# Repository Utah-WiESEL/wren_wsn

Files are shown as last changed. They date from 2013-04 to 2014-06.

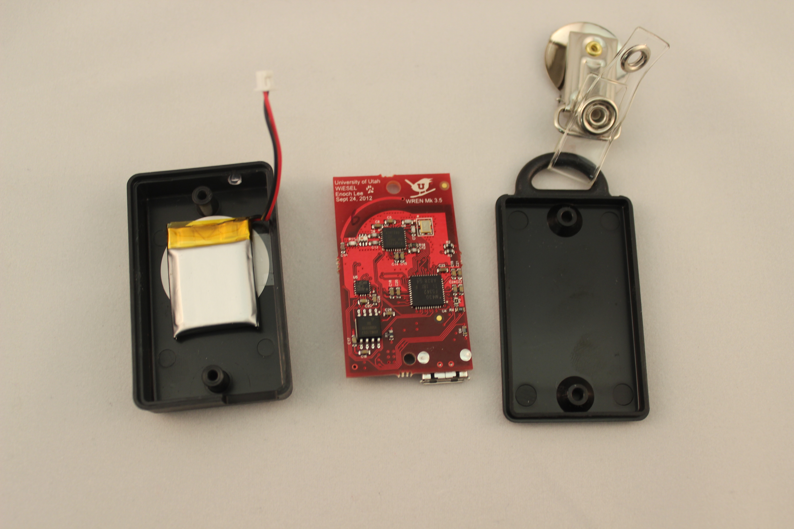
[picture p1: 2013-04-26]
wren_mote/images/image2.JPG

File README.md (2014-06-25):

wren_wsn
========

Wireless Ranging Enabled Node (WREN) is a new low cost, TinyOS compatible platform. Our main goal is to create a scalable WSN for human contact data for disease spreading simulations. This platform solves several issues when compared to commercially available sensors, such as the TelosB and Irene, in scaling and rapid deployment strategies. It also requires little maintenance and does not need an existing support infrastructure.

The low cost and maintainability allow it to easily scale to a network of thousands of motes. It is built with consideration that the end user may not have technical/engineering knowledge of the system. Deploying a network this large takes less than one hour and recovery is just as simple, leading to a rapid data download process for fast, repeatable deployments.

The system has several proximity based use cases besides contact networks. Other features such as motion tracking using the accelerometer, radio strength signal indication (RSSI), and low power usage can be made advantageous for several projects.

The purpose of this Wiki is to provide the source for our hardware, software, and instructions to get the system up and running.

For more info:

http://wiesel.ece.utah.edu/media/documents/pdf/2012/12/13/sensys-demo-2012.pdf

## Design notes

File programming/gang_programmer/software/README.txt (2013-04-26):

When programming, if only one WREN is attached,
	Disable all other 'open' ports.

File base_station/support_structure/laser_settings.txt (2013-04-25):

Laser Cutter Specs:
	60w
	Auto Focus (on)

1/4 in. wood (light color)
	speed:		30-34%
	power:		100%
	frequency:	500Hz
	
1/8 in. acrylic (clear)
	speed:		20%
	power:		100%
	frequency:	5000Hz
	
1/16 in. acrylic (clear)
	speed:		35%
	power:		40%
	frequency:	5000Hz

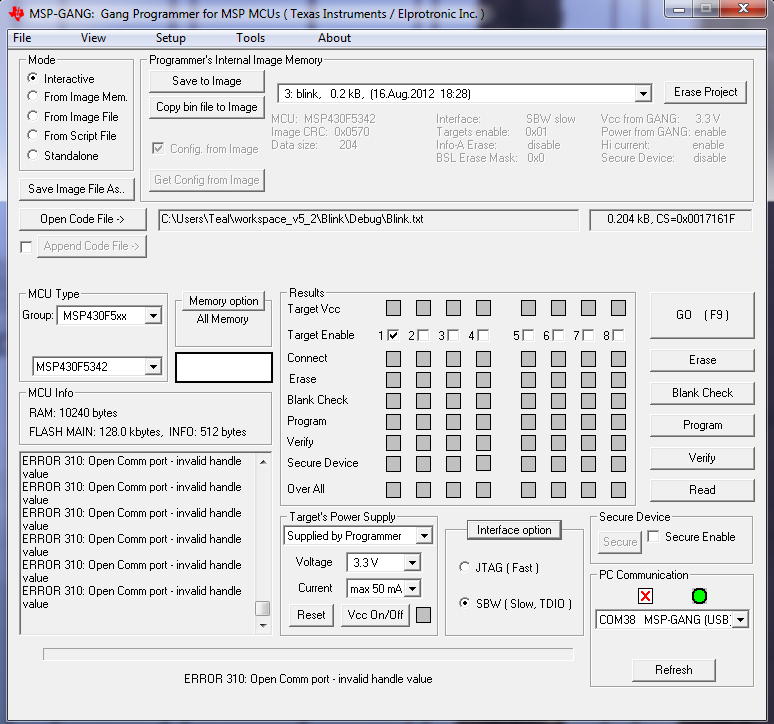
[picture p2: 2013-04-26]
programming/gang_programmer/software/Main Program.PNG

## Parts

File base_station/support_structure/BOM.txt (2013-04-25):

Bill of Materials (1x Base Station):

Wood (if using a laser, wood lighter in color will cut cleaner):

	Birch Project Panel Plywood:
		1/4 in. x 2 ft. x 4 ft. (x2)
	
	Dowels:
		1/2 in. x 48 in. (x6)

Hardware:
	Wood Screws:
		#4 x 1/2 in. Flat Head Phillips (30x) - used to mount PCB blades onto wood base
		
		#6 x 1 in. Flat Head Phillips (12x) - used to mount stack legs onto wooden base
		
	Drywall Screws:
		1-1/4 x 8 GA Coarse Thread (16x) - used to mount wooded support onto wooded base
	
	Power Mounting - used for mounting PSU and AC connector onto wooden base
		Switch Plate Screws:
			#6-32 x 1 in.  (x4)
	
		Machine Screw Nuts:
			#6-32 (x4)
			
		Flat Washers:
			#6 (x8)
	
Glue:
	Any generic wood glue

Other:

	Trim Tray - used for diluting wood glue
	Small Paint Brushes - used for applying glue
	Rags - used to wipe off excess glue

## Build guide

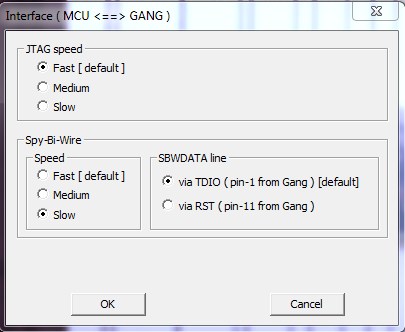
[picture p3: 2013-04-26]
programming/gang_programmer/software/Setup - Interface.PNG

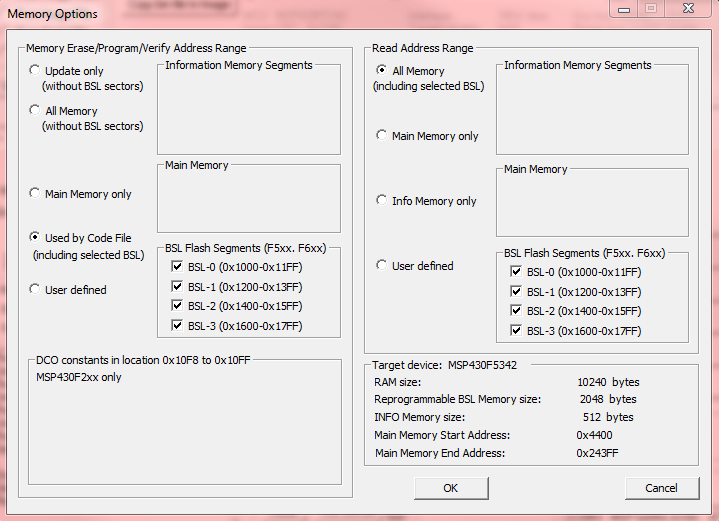
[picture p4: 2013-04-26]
programming/gang_programmer/software/Setup - Memory Options - For BSL.PNG

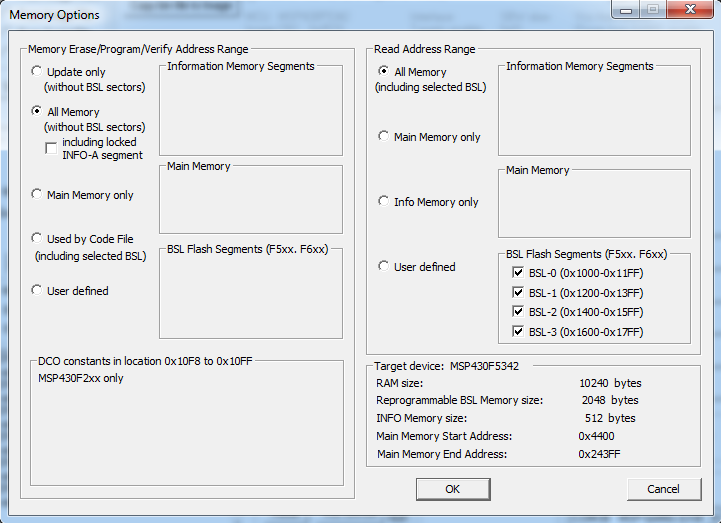
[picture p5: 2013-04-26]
programming/gang_programmer/software/Setup - Memory Options - For Others.PNG

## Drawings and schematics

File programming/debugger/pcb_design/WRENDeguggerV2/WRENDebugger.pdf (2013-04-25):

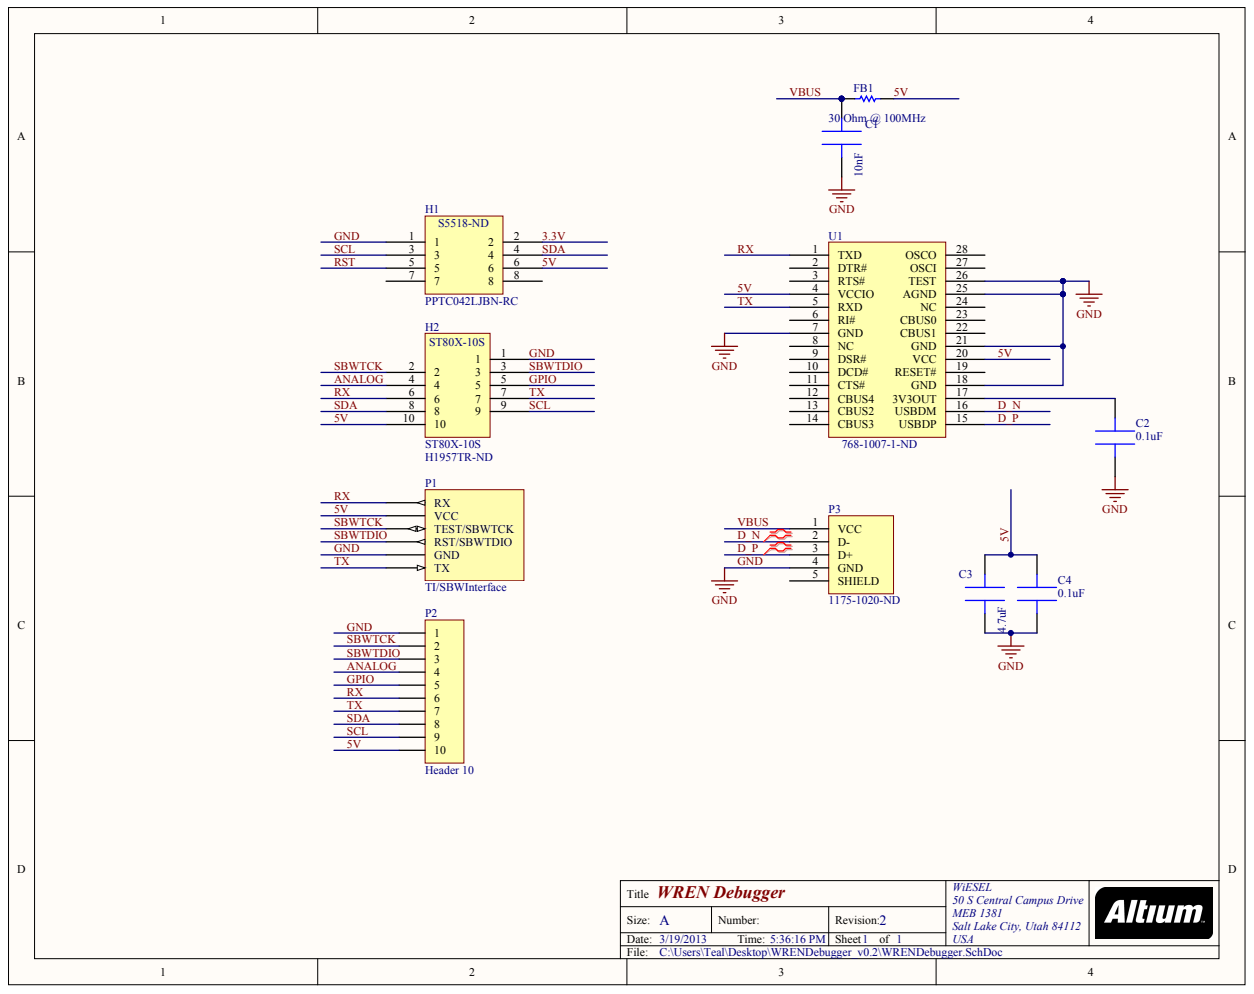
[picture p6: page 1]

WREN Debugger Title | WiESEL 50 S Central Campus Drive MEB 1381 Salt Lake City, Utah 84112 USA

Size: A | Number: | Revision: 2
Date: 3/19/2013 Time: 5:36:16 PM | | Sheet 1 of 1

C:\Users\Teal\Desktop\WRENDebugger_v0.2\WRENDebugger.SchDoc

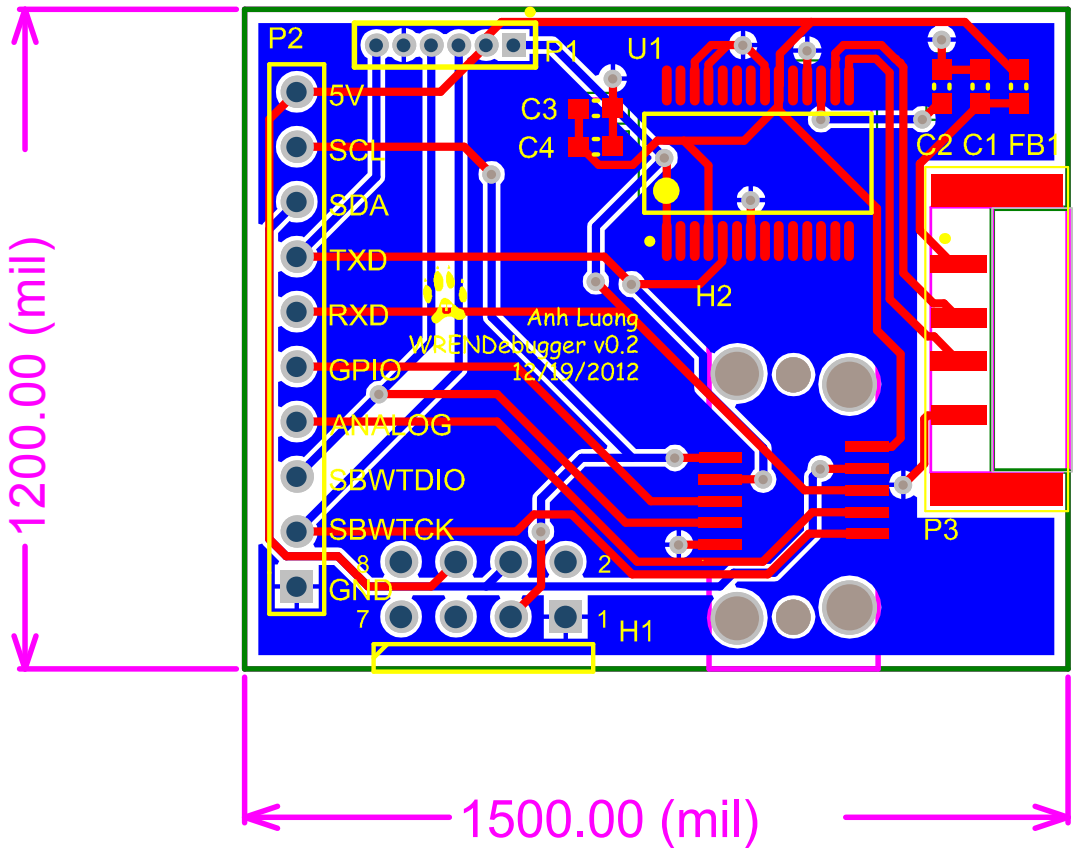
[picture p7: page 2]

Description | Footprint | Quantity | Supplier Part Number 1
MURATA - GRM188R71H103KA01D -CAPACITOR, 0603, 10NF, 50V, REEL 4000 | CAPC1608X09N (0603) | 1
Capacitor 0603 0.1uF | CAPC1608X09N (0603) | 2
CAP CER 4.7UF 6.3V Y5V 0603 | CAPC1608X09N (0603) | 1
FERRITE CHIP BEAD 30 OHM SMD | CAPC1608X09N (0603) | 1 | 445-2181-2-ND
CONN FEMALE 8POS DL .1" R/A TIN | S5518-ND | 1
CONN PLUG 10POS VERT CRADLE SMD | ST80X-10S | 1 | H1957TR-ND
TI MSP430 Programming Interface | SAMTEC/ SMS-106-01-G-S | 1
Header, 10-Pin | HDR1X10 | 1
CONN USB A TYPE ULTRA FLAT T/ H | usbA | 1 | 1175-1020-ND
IC USB FS SERIAL UART 28-SSOP | SOP65P780X200-28N | 1 | 768-1007-1-ND

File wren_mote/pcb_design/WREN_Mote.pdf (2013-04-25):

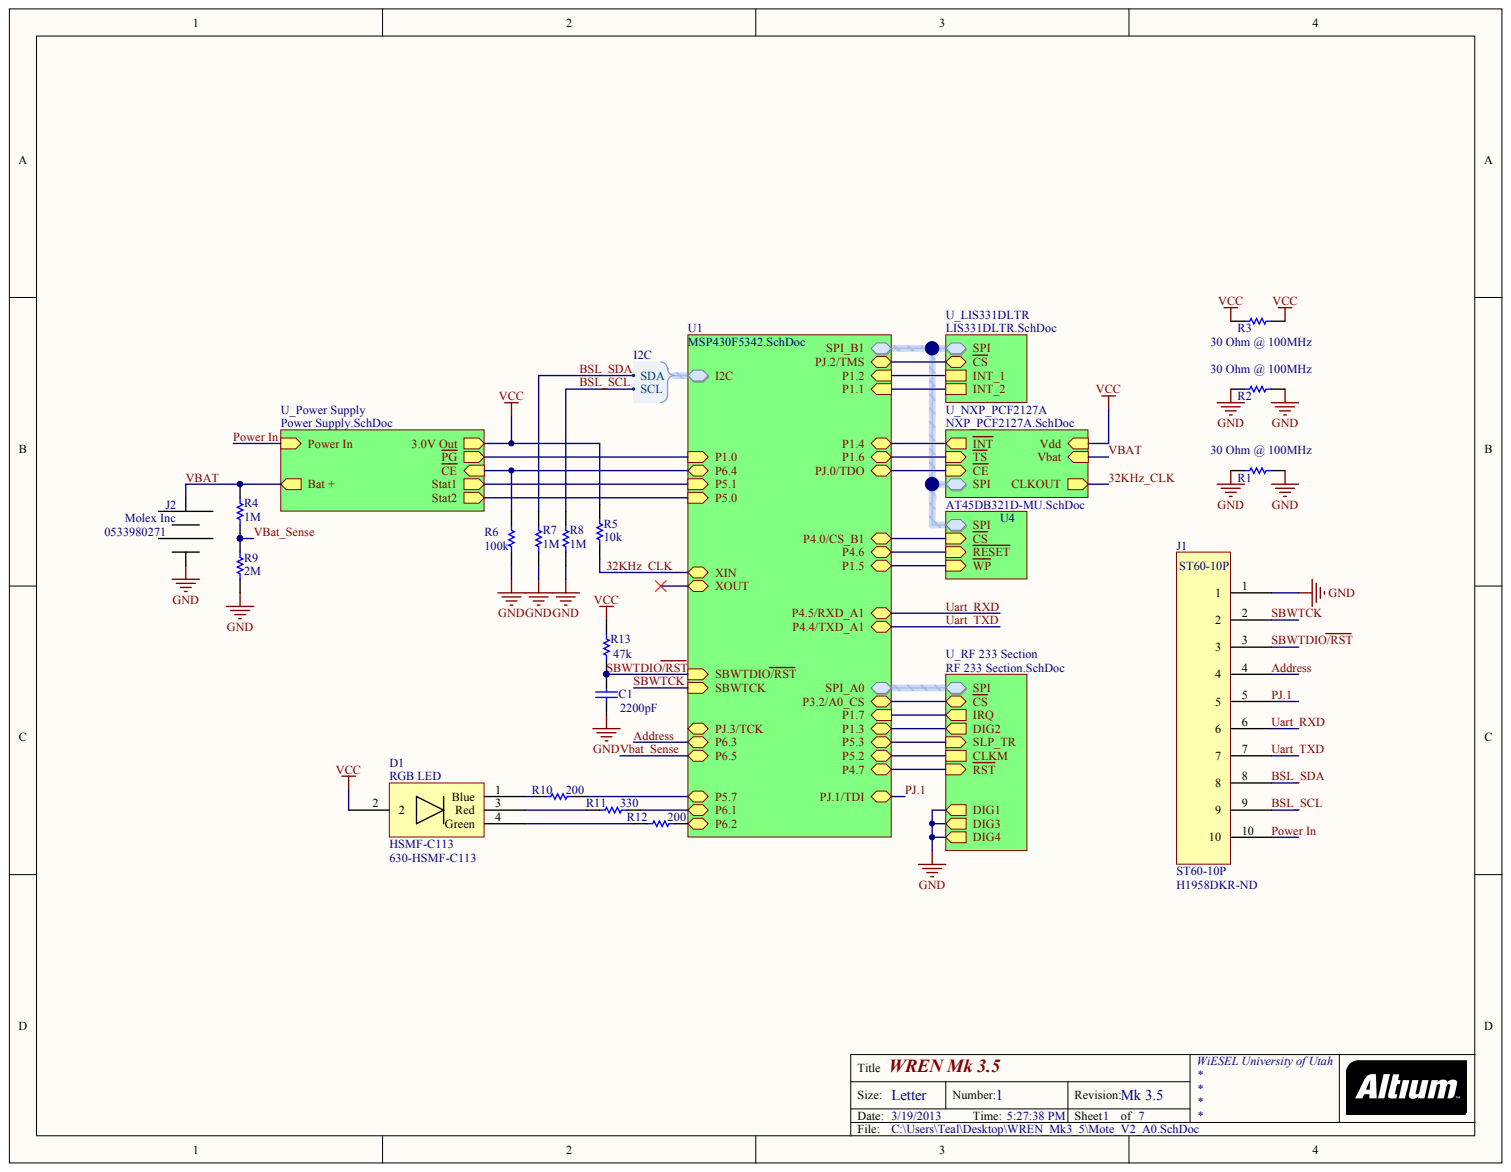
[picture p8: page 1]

P430F5342.SchDoc
PJ.0/TDO PJ.1/TDI PJ.2/TMS

U_Power Supply Power Supply.SchDoc

32KHz_CLK
Power In SBWTCK SBWTDIO/RS

PJ.3/TCK SBWTDIO/RS
SBWTCK

WiESEL University of Utah *** *

Letter | Revision:

3/19/2013 Time: 5:27:38 P M | Sheet of

C:\Users\Teal\Desktop\WREN_Mk3_5\Mote_V2_A0.SchDoc

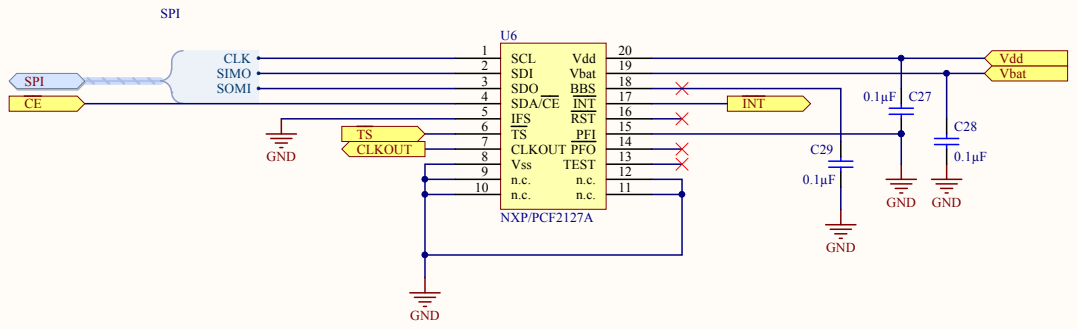
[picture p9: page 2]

n.c.

WiESEL University of Utah ***

C:\Users\Teal\Desktop\WREN_Mk3_5\NXP_PCF2127A.SchDoc

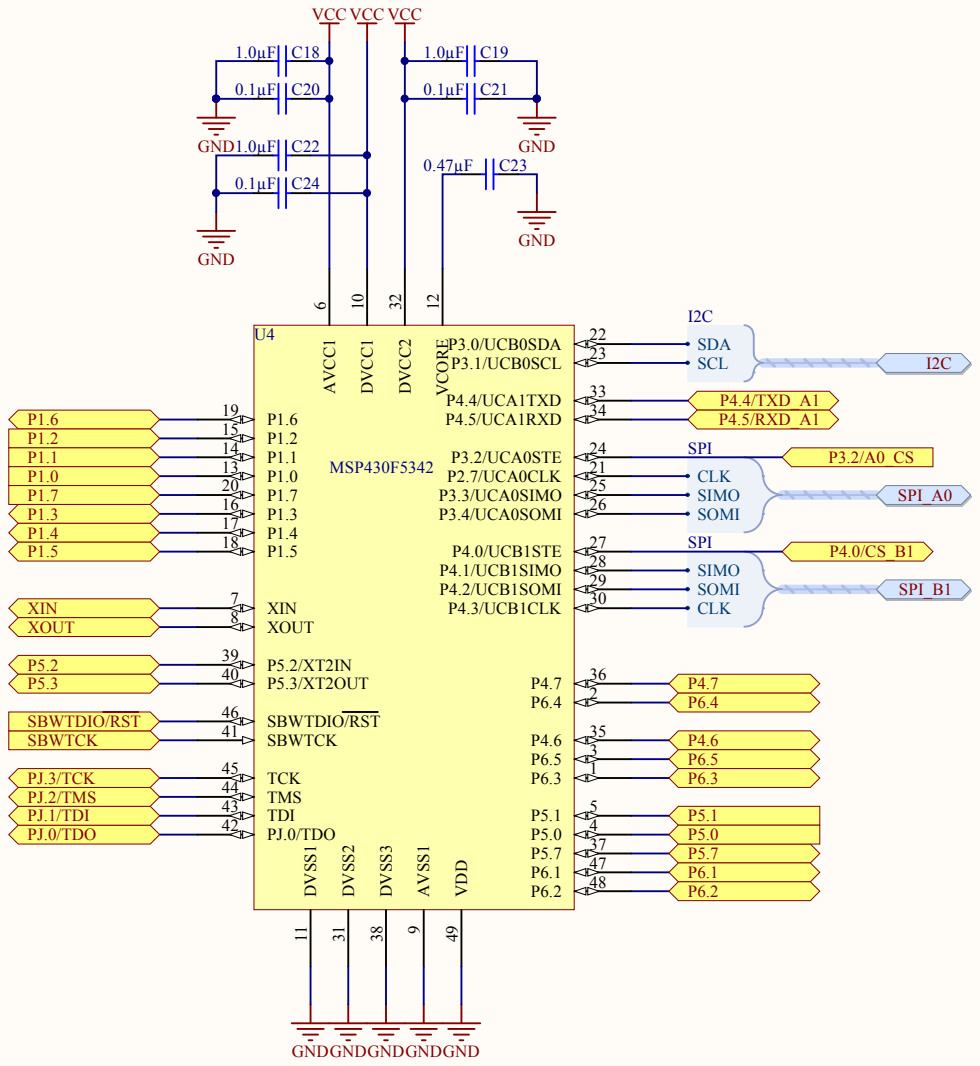
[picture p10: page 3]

Title WREN Mk 3.5 | WiESEL University of Utah *

Size: | Number: 3 | Mk 3.5

Date: 3/19/2013 Time: 5:27:38 PM | | Sheet of 7

C:\Users\Teal\Desktop\WREN_Mk3_5\MSP430F5342.SchDoc

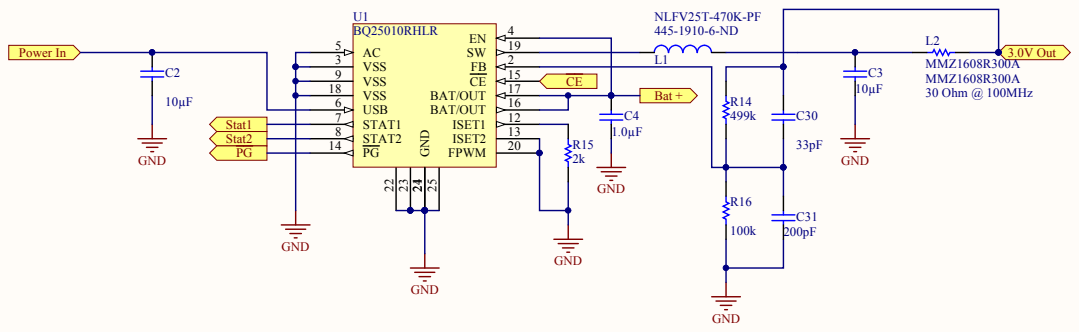
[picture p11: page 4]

WiESEL University of Utah ***

C:\Users\Teal\Desktop\WREN_Mk3_5\Power Supply.SchDoc

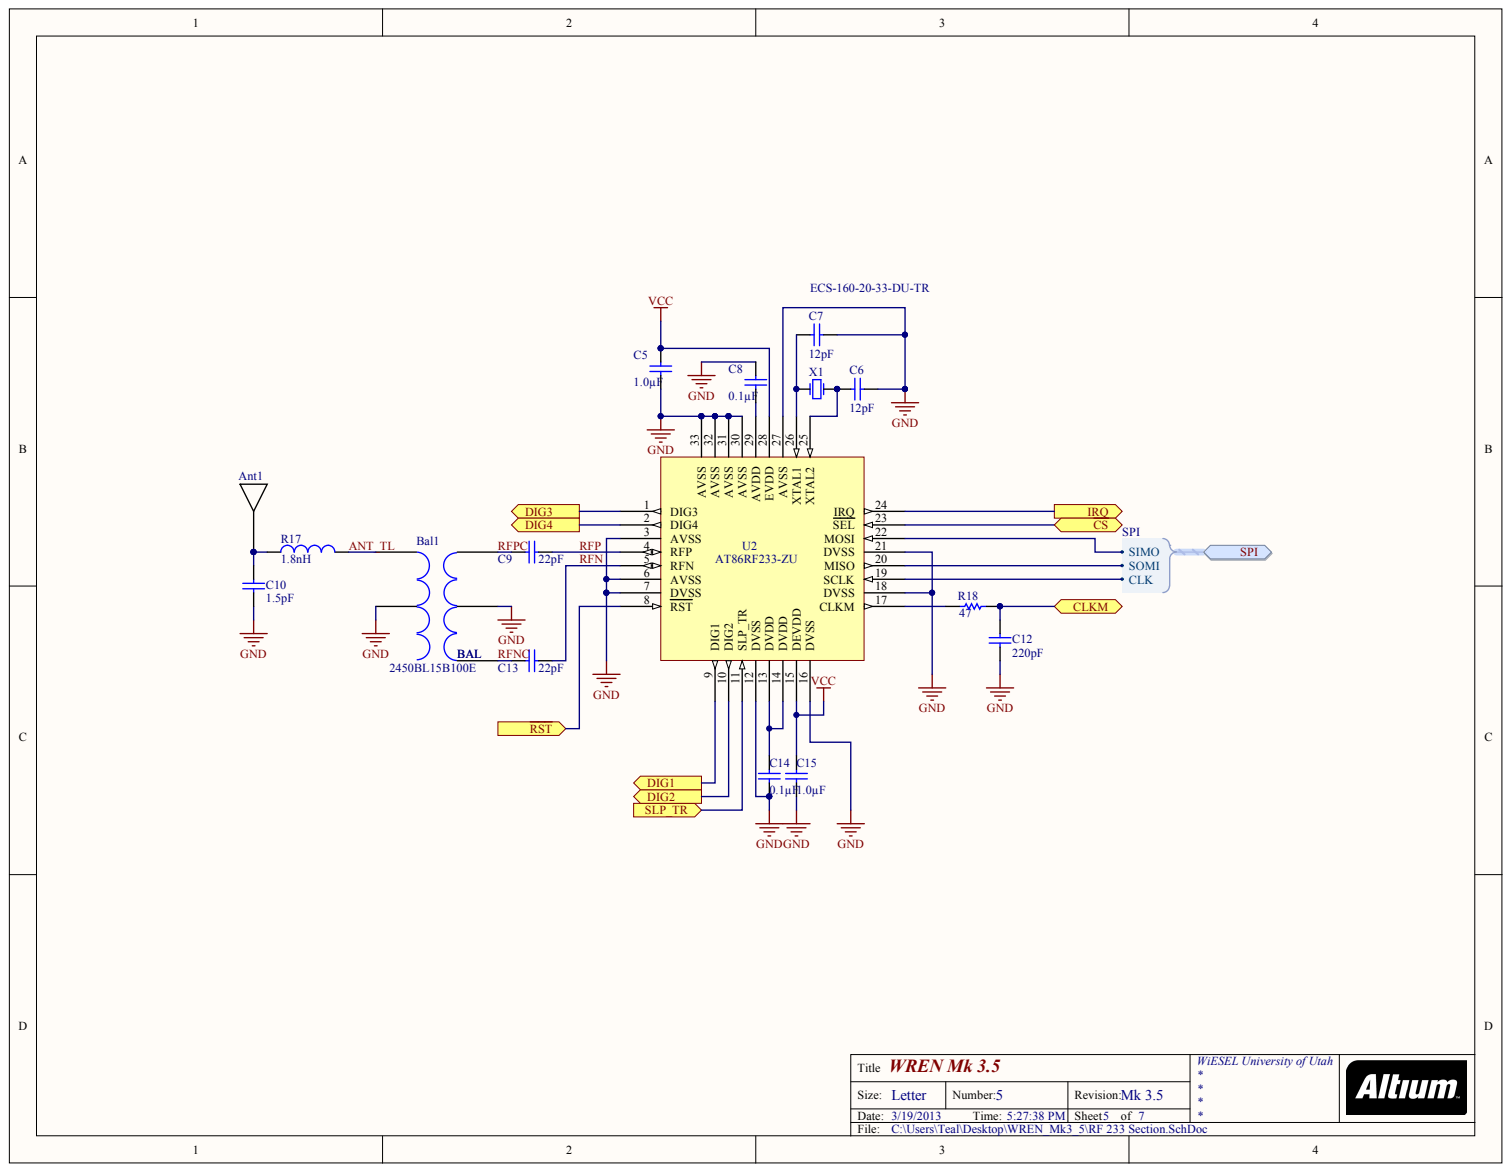
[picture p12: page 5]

TAL2 25 XTAL1 26 AVSS 27 EVDD 28 AVDD 29 AVSS 30 AVSS 31 AVSS 32 AVSS 33

DVSS 16 CLKM 17 DVSS 18 SCLK 19 MISO 20 DVSS 21 MOSI 22 SEL 23 IRQ X

RFP 4

RFN | RFN 5

AVSS 6

RST 8

Title WREN Mk 3.5 | WiESEL University of Utah *

Size: | Number: 5 | Mk 3.5

Date: 3/19/2013 Time: 5:27:38 PM | | Sheet of 7

C:\Users\Teal\Desktop\WREN_Mk3_5\RF 233 Section.SchDoc

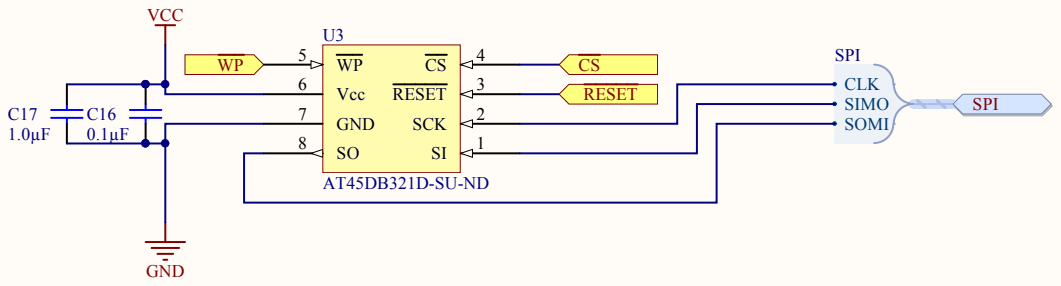
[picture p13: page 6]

WiESEL University of Utah ***

C:\Users\Teal\Desktop\WREN_Mk3_5\AT45DB321D-MU.SchDoc

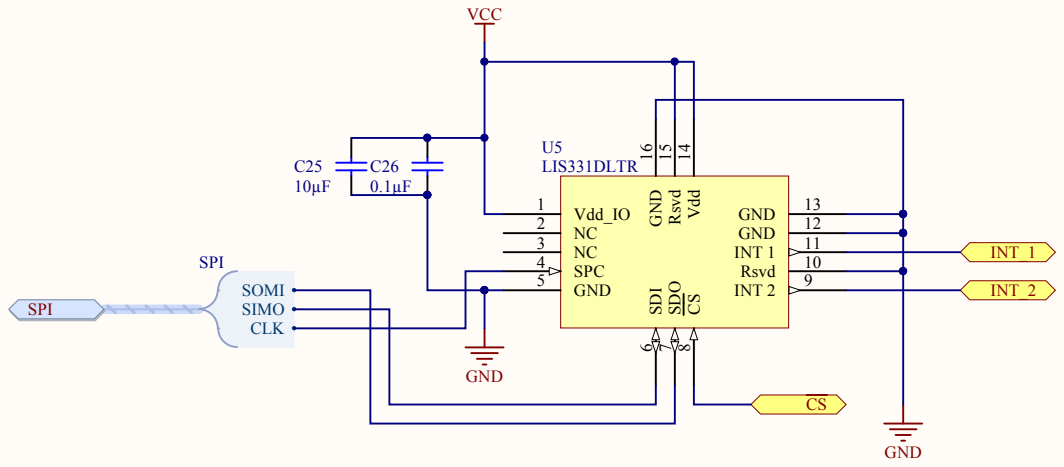
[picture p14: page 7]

WiESEL University of Utah ***

C:\Users\Teal\Desktop\WREN_Mk3_5\LIS331DLTR.SchDoc

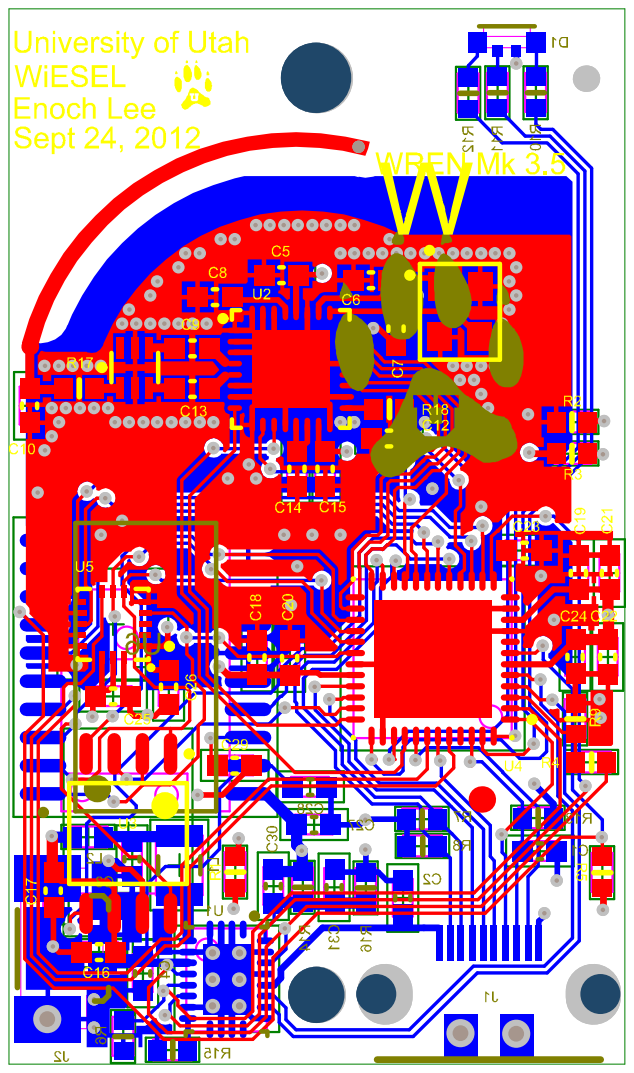
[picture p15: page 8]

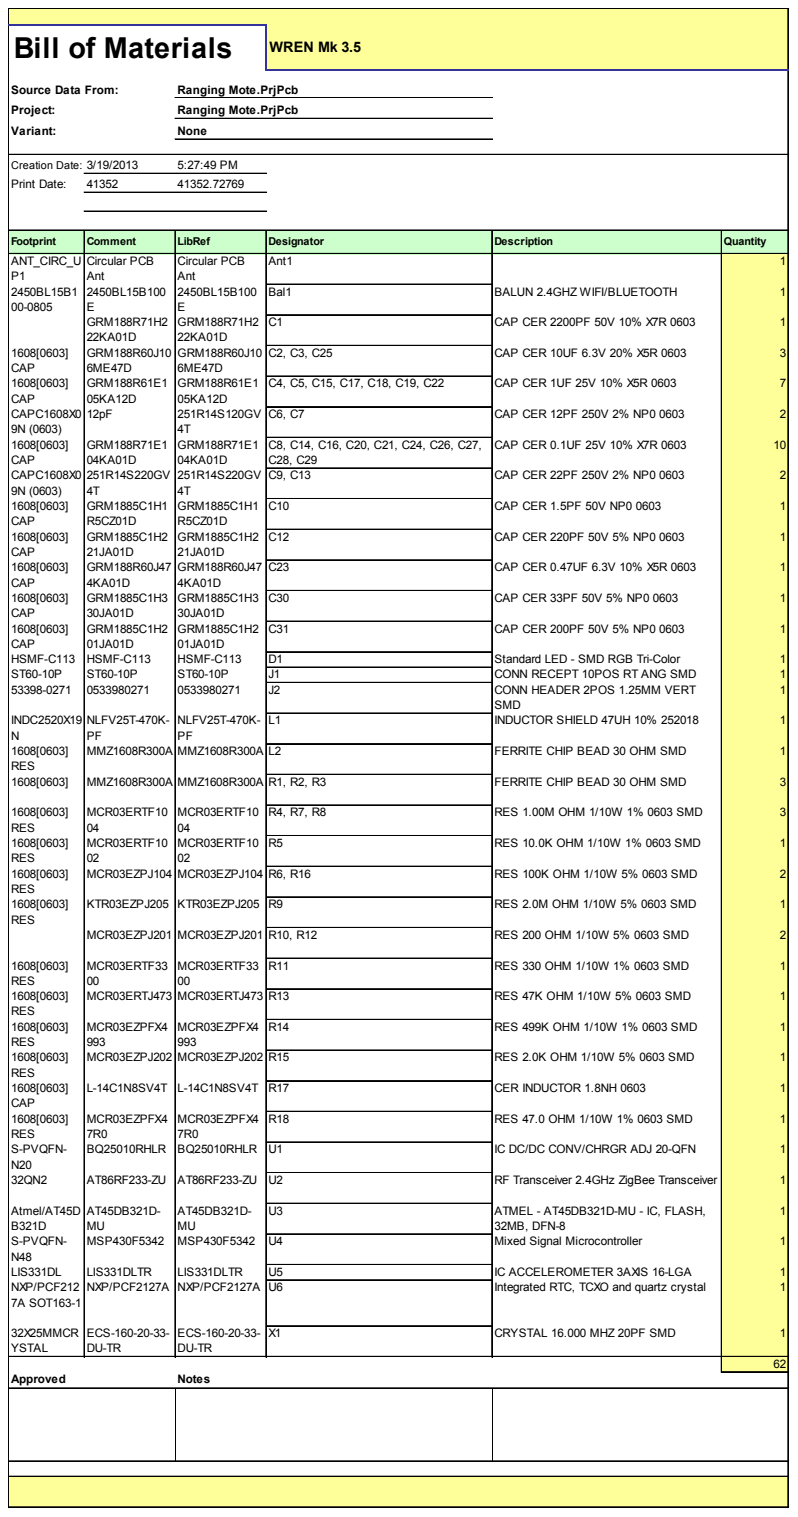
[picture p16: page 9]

Footprint | Comment | LibRef | Designator | Description | Quantity

Ant1 | | 1

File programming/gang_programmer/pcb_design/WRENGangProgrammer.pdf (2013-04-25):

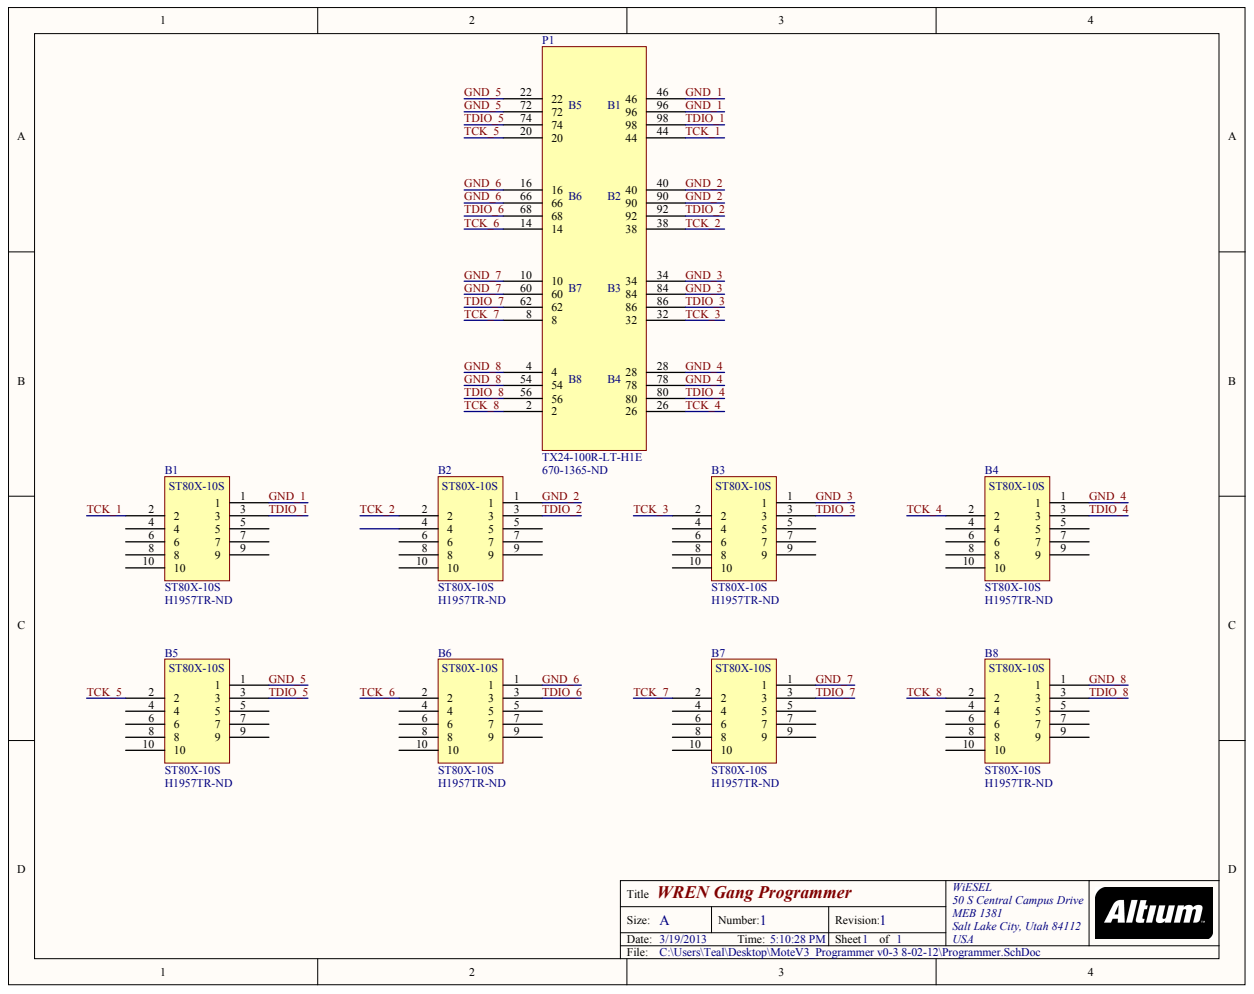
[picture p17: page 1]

WREN Gang Programmer Title | WiESEL 50 S Central Campus Drive MEB 1381 Salt Lake City, Utah 84112 USA

Size: A | Number: 1 | Revision: 1
Date: 3/19/2013 Time: 5:10:28 PM | | Sheet 1 of 1

C:\Users\Teal\Desktop\MoteV3_Programmer v0-3 8-02-12\Programmer.SchDoc


Comment | Description | Designator | Footprint | LibRef | Quantity

ST80X-10S | CONN PLUG 10POS VERT CRADLE SMD | B1, B2, B3, B4, B5, B6, B7, B8 | ST80X-10S | ST80X-10S | 8

TX24-100R-LT-H1E | CONN RCPT 1.27MM 100P1 | | TX24-100R-LT-H1E | TX24-100R-LT-H1E | 1

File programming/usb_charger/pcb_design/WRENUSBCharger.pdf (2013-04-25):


WREN USB Charger Title | WiESEL 50 S Central Campus Drive MEB 131 Salt Lake City, Utah 84112 USA

Size: A | Number: 1 | Revision: 1
Date: 3/19/2013 Time: 5:15:56 PM | | Sheet 1 of 1

C:\Users\Teal\Desktop\WRENUSBCharger\WRENUSBCharger.SchDoc


Comment | Description | Designator | Footprint | LibRef | Quantity

ST80X-10S | CONN PLUG 10POS VERT CRADLE SMD | H1 | ST80X-10S | ST80X-10S | 1

1002-015-01001 | CONN USB A TYPE ULTRAH2 | | usbA | 1002-015-01001 | 1

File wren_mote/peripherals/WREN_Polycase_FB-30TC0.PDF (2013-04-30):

TRUE R.058; TRUE R.032; SCALE:2:1; SHEET 1 OF 1

UNLESS OTHERWISE SPECIFIED: DIMENSIONS ARE IN MILLIMETERS SURFACE FINISH: TOLERANCES: LINEAR: ANGULAR: | FINISH: | DEBUR AND BREAK SHARP EDGES | DO NOT SCALE DRAWING | REVISION

NAME | SIGNATURE | DATE | | | | TITLE:
Q.A | | | | MATERIAL: | FB-30TC0 WEIGHT: DWG NO. | A2

DRAWN
CHK'D
APPV'D
MFG

SolidWorks Student Edition.
For Academic Use Only.



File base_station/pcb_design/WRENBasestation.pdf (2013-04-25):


WREN Basestation Title | WiESEL 50 S Central Campus Drive MEB 1381 Salt Lake City, Utah 84115 USA

Size: B | Number: | Revision: 3

Date: 3/19/2013 Time: 5:31:47 PM | | Sheet 1 of 1
File: C:\Users\Teal\Desktop\Mote_BaseStation_v0.3\BaseStation.SchDoc



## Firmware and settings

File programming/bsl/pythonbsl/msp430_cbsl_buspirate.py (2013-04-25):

#!/usr/bin/env python
# encoding: utf-8
"""
Copyright (c) 2013, University of Utah - Electrical and Computer Engineering - WiESEL
All rights reserved.

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
THIS SOFTWARE IS PROVIDED BY THE COPYRIGHT HOLDERS AND CONTRIBUTORS "AS IS" AND
ANY EXPRESS OR IMPLIED WARRANTIES, INCLUDING, BUT NOT LIMITED TO, THE IMPLIED
WARRANTIES OF MERCHANTABILITY AND FITNESS FOR A PARTICULAR PURPOSE ARE
DISCLAIMED. IN NO EVENT SHALL WiESEL BE LIABLE FOR ANY
DIRECT, INDIRECT, INCIDENTAL, SPECIAL, EXEMPLARY, OR CONSEQUENTIAL DAMAGES
(INCLUDING, BUT NOT LIMITED TO, PROCUREMENT OF SUBSTITUTE GOODS OR SERVICES;
LOSS OF USE, DATA, OR PROFITS; OR BUSINESS INTERRUPTION) HOWEVER CAUSED AND
ON ANY THEORY OF LIABILITY, WHETHER IN CONTRACT, STRICT LIABILITY, OR TORT
(INCLUDING NEGLIGENCE OR OTHERWISE) ARISING IN ANY WAY OUT OF THE USE OF THIS
SOFTWARE, EVEN IF ADVISED OF THE POSSIBILITY OF SUCH DAMAGE.
"""

########################################################################
### I2C Bootstrap Loader software for the msp430 embedded proccessor
###
### Anh Luong
### Based on Chris Liechti cc430 2010-04-11
### fixes from Colin Domoney
### cc430 port by Mark Hays 2010-04-11
### Based on tos-bsl version 1.39-telos-8
###

#'''exec' python $0 ${1+"$@"}
#'''
#'

import os, sys, time, string
#sys.path.append("/usr/lib/tinyos")
#//sys.path.append(os.environ.get("OSIAN_ROOT", "/opt/osian") + "/lib/python")
import serial
from I2C import *

VERSION = "CUSP BSL Programmer v0.0.1 2012-06-25"

# Maximum number of times to retry programming until we fail permanently
MAXIMUM_ATTEMPTS = 1

DEBUG = 3

ADDRESS = 0x48

def debug(level, fmt, *rest):
    "print debugging message"
    if DEBUG < level:
        return
    if rest:
        fmt = fmt % rest
    print >>sys.stderr, fmt.rstrip()
    sys.stderr.flush()

def hexl(items):
    "convert binary data to hex bytes for display"
    if not items:
        return "<None>"
    c = items[0]
    if isinstance(c, str) and len(c) == 1:
        ### convert chars to hex
        items = ["%02x" % ord(x) for x in items]
    elif isinstance(c, int):
        ### convert ints to hex
        items = ["%02x" % x for x in items]
    else:
        assert isinstance(c, str) and len(c) > 1
    return " ".join(items)

def i2caddr(addr, write=True):
    "convert standard address to 7 bit i2c address"
    if write:
        return ((addr << 1))
    else:
        return ((addr << 1) + 1)

### base exc
class BSLException(Exception):     pass

### serial port timeout
class BSLTimeout(BSLException):    pass

### BSL responses for txFrame
class BadHeader(BSLException):     pass
class BadChecksum(BSLException):   pass
class EmptyPacket(BSLException):   pass
class PacketTooLong(BSLException): pass
class UnknownError(BSLException):  pass
class BadBaudRate(BSLException):   pass
class BadResponse(BSLException):   pass # default for garbage resp

### serial proto errors for rxFrame
class BadRespHdr(BSLException):    pass
class BadRespLen(BSLException):    pass
class BadRespSum(BSLException):    pass
class BadRespCode(BSLException):   pass
class GarbledResp(BSLException):   pass

### BSL response messages for rxFrame
class BadFlashWrite(BSLException): pass
class FlashFail(BSLException):     pass
class VoltageChange(BSLException): pass
class Locked(BSLException):        pass
class BadPassword(BSLException):   pass
class BadByteWrite(BSLException):  pass
class UnknownCmd(BSLException):    pass
class Overrun(BSLException):       pass
class BadMessage(BSLException):    pass # default for garbage resp

### BSL response code in txFrame
XCODE = {
    0x51: BadHeader,
    0x52: BadChecksum,
    0x53: EmptyPacket,
    0x54: PacketTooLong,
    0x55: UnknownError,
    0x56: BadBaudRate,
}

### BSL response error in rxFrame
MCODE = {
    0x01: BadFlashWrite,
    0x02: FlashFail,
    0x03: VoltageChange,
    0x04: Locked,
    0x05: BadPassword,
    0x06: BadByteWrite,
    0x07: UnknownCmd,
    0x08: Overrun,
}

class LowLevel:
    "low level communication"

    DEFAULT_TIMEOUT = 0.5

    MAX_DATA_BYTES  = 240

    MAX_PI_SIZE = 256

    def __init__(self, aTimeout = None):
        """init bsl object, don't connect yet"""
        if aTimeout is None:
            self.timeout = self.DEFAULT_TIMEOUT
        else:
            self.timeout = aTimeout
        self.i2c  = None

        # max data size in txFrame
        self.maxData = self.MAX_DATA_BYTES

        # are we running BSL right now?
        self.inBSL = False

        self.address = ADDRESS

    def calcChecksum(self, data):
        """Calculates a CCITT CRC-16 checksum of data."""
        if not isinstance(data, str):
            data = "".join([chr(x) for x in data])
        crc = 0xffff
        for c in data:
            byte = ord(c)
            ### OVTA implementation
            ### See:
            ###   Efficient High Hamming Distance CRCs for Embedded Networks
            ###   Justin Ray and Philip Koopman
            ###   www.ece.cmu.edu/~koopman/pubs/ray06_crcalgorithms.pdf
            crc  = ((crc >> 8) | (crc << 8)) & 0xffff
            crc ^= byte
            crc ^= (crc & 0xf0) >> 4
            crc ^= (crc & 0x0f) << 12
            crc ^= (crc & 0xff) << 5
        return crc

    ### XXX everything from here up to txFrame was lifted from tos-bsl...
    ### XXX more or less

    def comInit(self, port):
        """
        Tries to open the serial port given and
        initialises the port and variables.
        """
        # Startup-Baudrate: 115200, 8, N, 1, timeout
        debug(2, "comInit port %s, 115200 8N1, timeout %s", port, self.timeout)

        # Init I2C object
        i2c = I2C(port, 115200, self.timeout)

        # Start Bit Banging Mode
        print "Entering binmode: ",
        if i2c.BBmode():
            print "OK."
        else:
            print "failed."
            sys.exit()

        # Start I2C
        print "Entering raw I2C mode: ",
        if i2c.enter_I2C():
            print "OK."
        else:
            print "failed."
            sys.exit()

        print "Configuring I2C."
        if not i2c.cfg_pins(I2CPins.POWER | I2CPins.PULLUPS):
            print "Failed to set I2C peripherals."
            sys.exit()
        if not i2c.set_speed(I2CSpeed._400KHZ):
            print "Failed to set I2C Speed."
            sys.exit()
        i2c.timeout(0.2)

        debug(2, "/comInit")

        self.i2c = i2c

    def close(self):
        print "Reset Bus Pirate to user terminal: "
        if self.i2c.resetBP():
            print "OK."
        else:
            print "failed."
            sys.exit()

    def __del__(self):
        #self.close()
        return

    def i2c_write_data(self, data, doResp=True):
        error = 0
        self.i2c.send_start_bit()
        for i in data:
            status = self.i2c.bulk_trans(1, [ord(i)])
            if status.find(chr(0x01)) != -1:
                print i + " NACK"
                error = 1
        self.i2c.send_stop_bit()
        if not doResp:
            debug(3, "/txFram !doResp")
            return
        if error:
            print "I2C command not acknowledged!"
            print [hex(ord(x)) for x in data]
            print "Reset Bus Pirate to user terminal: "
            if self.i2c.resetBP():
                print "OK."
            else:
                print "failed."
            raise BSLTimeout
        else:
            status = ord(status)
            if status:
                klass = XCODE.get(status, BadResponse)
                debug(3, "/txFrame resp %02x %s", status, klass.__name__)
                raise klass, status
            else:
                debug(3, "/txFrame ACK")

    def i2c_read_bytes(self, numbytes):
        data_out=[]
        while numbytes > 0:
            data_out.append(ord(self.i2c.read_byte()))
            self.i2c.send_ack()
            numbytes-=1
        return data_out

    def txFrame(self, data, doResp=True):
        "send data to BSL"
        if not isinstance(data, str):
            data = "".join([chr(x) for x in data])
        n = len(data)
        assert n <= self.MAX_PI_SIZE
        s = self.calcChecksum(data)
        f = chr(i2caddr(self.address)) + chr(0x80) + chr(n & 0xff) + chr(n >> 8) + data + chr(s & 0xff) + chr(s >> 8)
        debug(3, "txFrame %s", hexl(f))
        self.i2c_write_data(f)
        if not doResp:
            debug(3, "/txFrame !doResp")
            return

    def rxFrame(self):
        "get response from BSL"
        "send start bit"
        self.i2c.send_start_bit()
        self.i2c.bulk_trans(1, [i2caddr(self.address, False)])
        "receive first 4 bytes"
        h = self.i2c_read_bytes(4)
        if len(h) != 4:
            raise BSLTimeout
        debug(3, "rxFrame Head %s", hexl(h))
        if h[0] != 0x00:
            raise BadRespHdr, h[0]
        if h[1] != 0x80:
            raise BadRespHdr, h[1]
        n = (h[3] << 8) | h[2]
        if not n:
            raise BadRespLen
        "receive data"
        p = self.i2c_read_bytes(n)
        debug(3, "rxFrame Data %d: %s", n, hexl(p))
        if len(p) != n:
            raise BadRespLen
        "checksum"
        s = self.i2c_read_bytes(2)
        if len(s) != 2:
            raise BadRespSum, s
        s = (s[1] << 8) | s[0]
        debug(3, "rxFrame Sum %04x", s)
        "send nack for stopping"
        self.i2c.send_nack()
        "send stop bit"
        self.i2c.send_stop_bit()
        if s != self.calcChecksum(p):
            raise BadRespSum
        if not isinstance(p[0], int):
            c = ord(p[0])
        else:
            c = p[0]
        if c == 0x3a:
             p = p[1:]
             debug(3, "/rxFrame resp %s", hexl(p))
        elif c == 0x3b:
            if len(p) != 2:
                raise GarbledResp, p
            if not isinstance(p[1], int):
                c = ord(p[1])
            else:
                c = p[1]
            if c:
                klass = MCODE.get(c, BadMessage)
                debug(3, "/rxFrame Msg %02x %s", c, klass.__name__)
                raise klass
            else:
                debug(3, "/rxFrame Msg SUCCESS")
                return
        else:
            raise BadRespCode, c
        return p

class BSL(LowLevel):
    "Implements (most) BSL commands using txFrame and rxFrame"

    CMD_BAUD_RATE     = 0x52 # x Won't implement
    CMD_RX_DATA       = 0x10 # - Implemented
    CMD_RX_DATA_FAST  = 0x1b # - Implemented
    CMD_RX_PASSWD     = 0x11 # - Implemented
    CMD_ERASE_SEGMENT = 0x12 # - Implemented
    CMD_UNLOCK_INFO   = 0x13 # - Implemented
    CMD_MASS_ERASE    = 0x15 # - Implemented
    CMD_CRC_CHECK     = 0x16 # x Won't implement
    CMD_LOAD_PC       = 0x17 # - Implemented, RETA doesn't seem to return...
    CMD_TX_DATA       = 0x18 # - Implemented
    CMD_BSL_VERSION   = 0x19 # - Implemented
    CMD_TX_BUF_SIZE   = 0x1a # ? Doesn't work


    def __init__(self, *rest, **kw):
        LowLevel.__init__(self, *rest, **kw)
        self.fastrx = False
        self.passwd = None

    def massErase(self):
        "erase program flash"
        assert self.inBSL
        debug(2, "massErase")
        self.txFrame([self.CMD_MASS_ERASE])
        assert self.rxFrame() is None
        debug(3, "/massErase")

    def txPassword(self, passwd):
        "send BSL password"
        # XXX needs test, works after massErase
        assert self.inBSL
        passwd = passwd or self.passwd or ([0xff] * 32)
        debug(2, "txPassword %s", hexl(passwd))
        if not isinstance(passwd, str):
            passwd = "".join([chr(x) for x in passwd])
        self.txFrame(chr(self.CMD_RX_PASSWD) + passwd)
        assert self.rxFrame() is None
        debug(3, "/txPassword")

    def txBslVersion(self):
        "print out BSL version info"
        assert self.inBSL
        debug(2, "txBslVersion")
        try:
            self.txFrame(chr(self.CMD_BSL_VERSION))
            resp = self.rxFrame()
        except BSLTimeout:
            raise
        except BSLException:
            resp = ""
        if len(resp) != 4:
            debug(0, "BSL Version garbled or unimplemented, continuing anyway")
        else:
            #vid, ver, api, pi = [ord(x) for x in resp]
            vid, ver, api, pi = resp
            if vid == 0x00:
                vid = "Vendor %s(%02x)" % ("TI", vid)
            elif vid == 0x0C:
                vid = "Vendor %s(%02x)" % ("WiESEL", vid)
            else:
                vid = "Vendor %s(%02x)" % ("Unknown", vid)
            ver = "Interp %02x" % ver
            api = "API %02x%s" % (api, api & 0x80 and " Limited" or "")
            if pi == 0x27:
                pi = "PI I2C(%02x)" % pi
            elif pi < 0x20:
                pi = "PI TA_UART(%02x)" % pi
            elif pi < 0x50:
                pi = "PI USB(%02x)" % pi
            elif pi < 0x70:
                pi = "PI USCI_UART(%02x)" % pi
            else:
                pi = "PI Unknown(%02x)" % pi
            debug(0, "BSL Version: %s, %s, %s, %s", vid, ver, api, pi)
        debug(3, "/txBslVersion")

    def txData(self, addr, length):
        "get data from MCU memory"
        assert self.inBSL
        assert 0x000000 <= addr <= 0xffffff
        assert 0x0000 < length <= 0xffff
        ### CMD_TX_BUF_SIZE doesn't seem to work
        ### in practice, 260 seems to be the limit
        ### stick to 0x100 and lower
        assert 0 < length <= 0x100
        debug(2, "txData %04x @ %06x", length, addr)
        self.txFrame([self.CMD_TX_DATA,
                      (addr >>  0) & 0xff,
                      (addr >>  8) & 0xff,
                      (addr >> 16) & 0xff,
                      (length >> 0) & 0xff,
                      (length >> 8) & 0xff])
        ret = self.rxFrame()
        if len(ret) != length:
            raise GarbledResp, (len(ret), ret)
        debug(3, "txData resp %s", hexl(ret))
        debug(3, "/txData")
        return ret

    def _rxData(self, addr, data, slow):
        "write data into MCU memory"
        assert self.inBSL
        assert 0x000000 <= addr <= 0xffffff
        assert isinstance(data, str) and data
        ### CMD_TX_BUF_SIZE doesn't seem to work
        ### in practice, 260 seems to be the limit
        ### stick to 0x100 and lower
        assert 0 < len(data) <= 0x100
        debug(2, "rxData%s %d @ %06x: %s",
              (not slow) and " Fast" or "", len(data), addr, hexl(data))
        head = "".join([chr(slow and self.CMD_RX_DATA or self.CMD_RX_DATA_FAST),
                        chr((addr >>  0) & 0xff),
                        chr((addr >>  8) & 0xff),
                        chr((addr >> 16) & 0xff)])
        self.txFrame(head + data)
        if slow:
            assert self.rxFrame() is None
        debug(3, "/rxData")

    def rxData(self, addr, data):
        "program with verify"
        self._rxData(addr, data, not self.fastrx)

    def eraseSegment(self, addr):
        "erase a segment by address"
        assert self.inBSL
        assert 0x000000 <= addr <= 0xffffff
        debug(2, "eraseSegment %06x", addr)
        self.txFrame([self.CMD_ERASE_SEGMENT,
                      (addr >>  0) & 0xff,
                      (addr >>  8) & 0xff,
                      (addr >> 16) & 0xff])
        assert self.rxFrame() is None
        debug(3, "/eraseSegment")

    def _toggleLOCKA(self):
        "toggle the LOCKA bit"
        debug(3, "toggleLOCKA")
        self.txFrame(chr(self.CMD_UNLOCK_INFO))
        assert self.rxFrame() is None
        debug(3, "/toggleLOCKA")

    def _eraseInfoA(self):
        "erase info segment A"
        assert self.inBSL
        debug(3, "eraseInfoA")
        ### XXX toggling LOCKA doesn't seem to matter??
        self._toggleLOCKA()
        self.eraseSegment(0x001980)
        self._toggleLOCKA()
        debug(3, "/eraseInfoA")

    ### XXX this probably only works for:
    ### XXX   F5133, F5135, F6125, F6135, F6126, F5137, F6127, and F6137
    INFO_ADDRS = {
        "a": None,     # use eraseInfoA() for this one
        "b": 0x001900,
        "c": 0x001880,
        "d": 0x001800,
    }

    def eraseInfo(self, which="abcd"):
        "erase some/all of info segments A-D"
        assert self.inBSL
        assert isinstance(which, str) and which and len(which) <= 4
        d = { }
        for seg in which.lower():
            assert seg in self.INFO_ADDRS
            d.setdefault(seg)
        d = d.keys()
        d.sort()
        debug(2, "eraseInfo segs=%s", "".join(d))
        for seg in d:
            addr = self.INFO_ADDRS[seg]
            if addr is None:
                self._eraseInfoA()
            else:
                debug(2, "Erasing INFO %s", seg)
                self.eraseSegment(addr)
        debug(3, "/eraseInfo")

    def loadPC(self, addr, expectReturn=False):
        "jump to location"
        assert self.inBSL
        assert 0x000000 <= addr <= 0xffffff
        assert not (addr & 1)
        debug(2, "loadPC %06x", addr)
        self.txFrame([self.CMD_LOAD_PC,
                      (addr >>  0) & 0xff,
                      (addr >>  8) & 0xff,
                      (addr >> 16) & 0xff])
        ### XXX a RETA doesn't seem to return to BSL?
        ### XXX OK, just break ourself then
        self.inBSL = False
        debug(3, "/loadPC")

### this class lifted in its entirety from tos-bsl
class Segment:
    """store a string with memory contents along with its startaddress"""
    def __init__(self, startaddress = 0, data=None):
        if data is None:
            self.data = ''
        else:
            self.data = data
        self.startaddress = startaddress

    def __getitem__(self, index):
        return self.data[index]

    def __len__(self):
        return len(self.data)

    def __repr__(self):
        return "Segment(startaddress = 0x%04x, data=%r)" % (self.startaddress, self.data)
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

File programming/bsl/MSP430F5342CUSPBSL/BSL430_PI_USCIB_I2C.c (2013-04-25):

/*
 Copyright (c) 2013, University of Utah - Electrical and Computer Engineering - WiESEL
 All rights reserved.
 
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
 THIS SOFTWARE IS PROVIDED BY THE COPYRIGHT HOLDERS AND CONTRIBUTORS "AS IS" AND
 ANY EXPRESS OR IMPLIED WARRANTIES, INCLUDING, BUT NOT LIMITED TO, THE IMPLIED
 WARRANTIES OF MERCHANTABILITY AND FITNESS FOR A PARTICULAR PURPOSE ARE
 DISCLAIMED. IN NO EVENT SHALL WiESEL BE LIABLE FOR ANY
 DIRECT, INDIRECT, INCIDENTAL, SPECIAL, EXEMPLARY, OR CONSEQUENTIAL DAMAGES
 (INCLUDING, BUT NOT LIMITED TO, PROCUREMENT OF SUBSTITUTE GOODS OR SERVICES;
 LOSS OF USE, DATA, OR PROFITS; OR BUSINESS INTERRUPTION) HOWEVER CAUSED AND
 ON ANY THEORY OF LIABILITY, WHETHER IN CONTRACT, STRICT LIABILITY, OR TORT
 (INCLUDING NEGLIGENCE OR OTHERWISE) ARISING IN ANY WAY OUT OF THE USE OF THIS
 SOFTWARE, EVEN IF ADVISED OF THE POSSIBILITY OF SUCH DAMAGE.
 */

/*
 * Anh Luong
 * 06/25/2012
 */

extern void interpretCommand();

#include "BSL_Device_File.h"
#include "BSL430_PI.h"
#include "BSL430_Command_Interpreter.h"
#include "BSL430_Command_Definitions.h"

//errors
#define HEADER_INCORRECT (PI_COMMAND_UPPER + 0x01)
#define CHECKSUM_INCORRECT (PI_COMMAND_UPPER + 0x02)
#define PACKET_SIZE_ZERO (PI_COMMAND_UPPER + 0x03)
#define PACKET_SIZE_TOO_BIG (PI_COMMAND_UPPER + 0x04)
#define UNKNOWN_ERROR (PI_COMMAND_UPPER + 0x05)

#define MAX_BUFFER_SIZE 260

//#define SLAVE_ADDRESS 0x48
#define ADC

char verifyData(int checksum);

//I2C Interface specific functions
void receiveDataFromMaster(unsigned char);
void sendByte(char data);

char byStatusByte;
char RX_StatusFlags = RX_PACKET_ONGOING;
volatile int checksum = 0;

char *BSL430_ReceiveBuffer;
char *BSL430_SendBuffer;
unsigned int BSL430_BufferSize;
char RAM_TX_Buf[MAX_BUFFER_SIZE];
char RAM_RX_Buf[MAX_BUFFER_SIZE];

#define USCIB_I2C_VERSION 0x03
//const unsigned char BSL430_PI_Version = (BSL430_USCIB_I2C_PI + USCIB_I2C_VERSION);

unsigned char RxValue;
unsigned int rxdataPointer = 0;
unsigned int transmitBufferLength = 0;
unsigned int transmitPoint = 0;


/*******************************************************************************
 * *Function:    PI_init  - I2C
 * *Description: Initializes the I2C Slave
 *  Returns:      None
 *******************************************************************************/

void PI_init()
{

	BSL430_ReceiveBuffer = RAM_RX_Buf;
	BSL430_SendBuffer = &RAM_TX_Buf[4];
	rxdataPointer = 0;

    UCSCTL4 = SELA__REFOCLK + SELM__DCOCLK + SELS__DCOCLK;   // to do check SELA

    UCSCTL0 = 0x000;                                         // Set DCO to lowest Tap

    UCSCTL1 = DCORSEL_4;                                     // 8MHz nominal DCO
    UCSCTL5 = DIVM_0 + DIVS_0;
    UCSCTL2 = FLLD_2 | (((DCO_SPEED / ACLK_SPEED) / 4) - 1); // 8MHz

	// Set up address from ADC
#ifdef ADC
	P6SEL |= BIT3;
	REFCTL0 &= ~REFMSTR;
	ADC12CTL0 = ADC12ON+ADC12SHT0_12+ADC12MSC+ADC12REFON+ADC12REF2_5V;
	ADC12CTL1 = ADC12SHP+ADC12CONSEQ_2;         // Use sampling timer
	ADC12MCTL0 = ADC12INCH_3+ADC12SREF_1;
	volatile unsigned int i;
	for(i = 0; i < 0x30; i++);
	unsigned int sum = 0;
	for(i = 0; i < 16; i++)
	{
		ADC12CTL0 |= ADC12ENC;                  // Enable conversions
		ADC12CTL0 |= ADC12SC;                   // Start conversion
		while (!(ADC12IFG & BIT0));
		sum += ADC12MEM0;
	}
	sum >>= 9;
	if(sum == 0x00)
		sum++;
#endif

	TX_PORT_SEL |= RXD + TXD;                               // Assign I2C pins to USCI_B1
	UCZNCTL1 |= UCSWRST;                                    // Enable SW reset
	UCZNCTL0 = UCMODE_3 + UCSYNC;                           // I2C Slave, synchronous mode
#ifdef ADC
	UCZNI2COA = sum + UCGCEN;				    // Own Address is 048h
#else
	UCZNI2COA = 0x48 + UCGCEN;								// Own Address is 048h
#endif
	UCZNCTL1 &= ~UCSWRST;                                   // Clear SW reset, resume operation

	UCZNIE |= UCTXIE + UCRXIE + UCSTPIE + UCSTTIE;

} //init

/*******************************************************************************
 * *Function:    PI_receivePacket
 * *Description: Handles the sequence of START, DATA, RESTART and then SENDS DATA
 *             and then STOP
 *  Returns:      None
 *
 *******************************************************************************/
#define I2C_START_CONDITION_RECEIVED 0x06
#define I2C_STOP_CONDITION_RECEIVED  0x08
#define I2C_DATA_RECEIVED            0x0A
#define I2C_TRANSMIT_BUFFER_EMPTY    0x0C
char PI_receivePacket()
{
	RX_StatusFlags = RX_PACKET_ONGOING;

	while (RX_StatusFlags == RX_PACKET_ONGOING)
	{
		switch (UCZIV)
		{
		case I2C_START_CONDITION_RECEIVED:
			transmitPoint = 0;               //Start Condition Received
			rxdataPointer = 0;
			break;

		case I2C_STOP_CONDITION_RECEIVED:    //Stop Condition Received
			break;

		case I2C_DATA_RECEIVED:
			RxValue = UCZRXBUF;              //Data Received
			receiveDataFromMaster(RxValue);
			break;

		case I2C_TRANSMIT_BUFFER_EMPTY:
			if (transmitPoint < transmitBufferLength)
			{
				UCZTXBUF = RAM_TX_Buf[transmitPoint++];
			}
			break;

		default:          break;

		} // switch
	} // while
	return RX_StatusFlags;
}

/*******************************************************************************
 * *Function:    receiveDataFromMaster  - I2C routine
 * *Description: Retrieves the format info, data etc from the received data and
 *             sets error flags if format is wrong - wrong checksum, wrong header etc
 *             and stripes the data bytes from the format characters and headers
 *
 *             eg: 0x80 0x01 0x00 0x19 0xE8 0x62 gets converted to
 *                 Header - 0x80
 *                 Length - 0x01
 *                 Command - 0x19
 *                 Checksum - CKL-0xE8
 *                            CKH-0x62
 * *Returns: None
 *
 *******************************************************************************/
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

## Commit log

2013-04-25 Added first set of files to repo. Gerbers, schematics, software.
    [BaseStation.GBL, BaseStation.GBO, BaseStation.GBP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]
2013-04-30 add model of the case, and images for base station and assembly process
2014-06-20 WREN Applications
    Adding User Commander, Command Controller, Mote Sleeper, Wireless
    Downloader, Mote Client applications
